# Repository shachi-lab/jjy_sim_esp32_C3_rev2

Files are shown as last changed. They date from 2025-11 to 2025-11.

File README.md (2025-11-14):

# JJY-SIM Rev.2 (JJY Time Signal Simulator for ESP32-C3)

[🇯🇵 日本語版はこちら](README_ja.md)

**JJY-SIM** is a compact time signal simulator that emulates Japan's JJY standard radio time code (40 kHz / 60 kHz) using an ESP32-C3 and the Arduino framework.  
It fetches accurate NTP time and generates a modulated JJY signal via PWM. 
**Rev.2** introduces an H-bridge RF output for higher transmission power and improved stability.

<a href="./images/jjy_sim_rev2_board_w800.jpg">
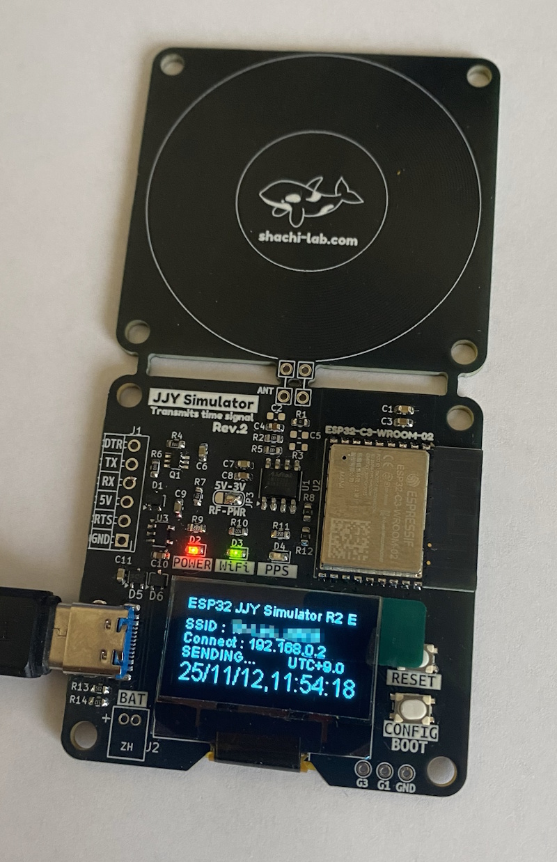
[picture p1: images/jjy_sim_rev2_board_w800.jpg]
JJY Simulator Board
</a><br/>

---

## 🪛 Features

- Compact design using **ESP32-C3 + Arduino**  
- Easy Wi-Fi setup with single-button **AP mode**  
- **OLED display** shows current time and sync status  
- Automatic time synchronization via **NTP**  
- Switchable **JJY 40 kHz (East Japan) / 60 kHz (West Japan)** output  
- Signal transmitted from a built-in **mini antenna** on the board  
- **H-bridge driver** provides high output power (⚠ may transmit farther than expected)  
- Configurable through a **web browser setup page**  
- Supports **local time zones (UTC offset)** and **DST (Daylight Saving Time)**

---

## ⚙️ How to Build

1. **Set up ESP32 boards in Arduino IDE**
   - Boards Manager URL:  
     `https://dl.espressif.com/dl/package_esp32_index.json`
   - Target board: **ESP32-C3 Dev Module**

2. **Install required libraries**
   - [WiFiManager](https://github.com/tzapu/WiFiManager)（v2.0.17 recommended）
   - [ESP8266 and ESP32 OLED driver for SSD1306 displays](https://github.com/ThingPulse/esp8266-oled-ssd1306) (v4.6.0 recommended)

3. **Open the sketch**
   - File: `JJY_Sim_ESP32_C3_REV2.ino`

4. **Compile and upload**
   - Select the correct board and COM port.
   - Click “Upload”.

> 💡 **Note:**  
ESP32-C3 uses its built-in **native USB-UART** for flashing and serial communication.  
On Windows, you may need the official **Espressif USB driver**:  
[Download here](https://www.espressif.com/en/support/download/other-tools)

> ⚠️ **First Boot:**  
During the first startup immediately after writing the program, the system builds a file system in the internal flash memory. Because of this, there may be no response for several tens of seconds, making it appear as if the system has “hung.”
Once the process is complete, the system will automatically reboot, and from then on it will start up normally. If it does not reboot automatically, please press the RESET button to restart.

---

## 📶 Wi-Fi Setup

- After power-on or reset, press the **CONFIG** switch within 5 seconds.  
- An AP named `ESP32_XXXXXXXX` starts (password: `password`).  
- Connect from your phone or PC → captive portal.
- [WiFi Configure] page → set your Wi-Fi SSID and password. 
- [Setup] page allows configuration of BAND, local time, and DST settings.

---

## 🕒 Operation

- If no button is pressed, the device connects to your Wi-Fi automatically.  
- Retrieves time from NTP server.  
- Displays current time on OLED.  
- Starts PWM JJY signal output synchronized to the next 0 second.  
- Place your radio-controlled clock near the antenna and press its “Receive” button.

---

## 🔌 Pin Assignments

| Function | GPIO | Description |
|---|---|---|
| JJY PWM Output | 10, 4 | Modulated signal (A/B for H-bridge) |
| CONFIG Switch | 9 | Wi-Fi setup (shared with BOOT) |
| ACT LED | 5 | Activity indicator |
| IND LED | 0 | Status indicator |
| OLED Reset | 2 | OLED hardware reset |
| OLED SDA | 7 | I²C data |
| OLED SCL | 6 | I²C clock |

---

## 🧾 File Structure

All Arduino source files are in the **`Source/`** folder:

```
JJY_Sim_ESP32_C3_REV2.ino   // Main sketch
wire_compat.h               // I²C compatibility header for ESP32-C3
shachi-lab_logo.h           // Logo bitmap
src/WiFiManager/            // Several files in this folder
```

---

## 📚 Dependencies

- [ESP8266 and ESP32 OLED driver for SSD1306 displays](https://github.com/ThingPulse/esp8266-oled-ssd1306)

---

## 🧰 Hardware Data

KiCad design files are included in the **`KiCad/`** folder.  
- Compatible with **KiCad v9** (older versions not supported)  
- **Gerber files** for fabrication are located in `KiCad/PLOT/`.

---

## ⚠️ Legal Notice

This device emits real low-frequency RF signals.  
Please use it responsibly and ensure compliance with local radio regulations.

---

## 🔗 Related Links

- Blog article (Japanese, detailed build notes):  
  👉 https://blog.shachi-lab.com/047_jjy_sim_rev2/

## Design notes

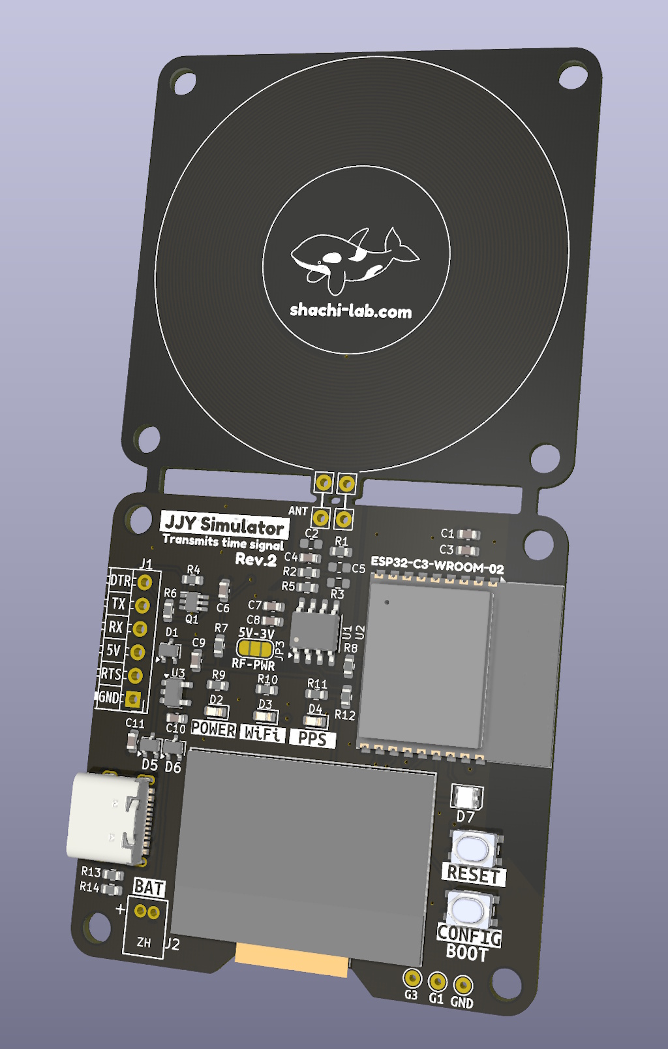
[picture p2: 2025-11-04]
KiCad/esp32_JJY_sim_C3_rev2.jpg

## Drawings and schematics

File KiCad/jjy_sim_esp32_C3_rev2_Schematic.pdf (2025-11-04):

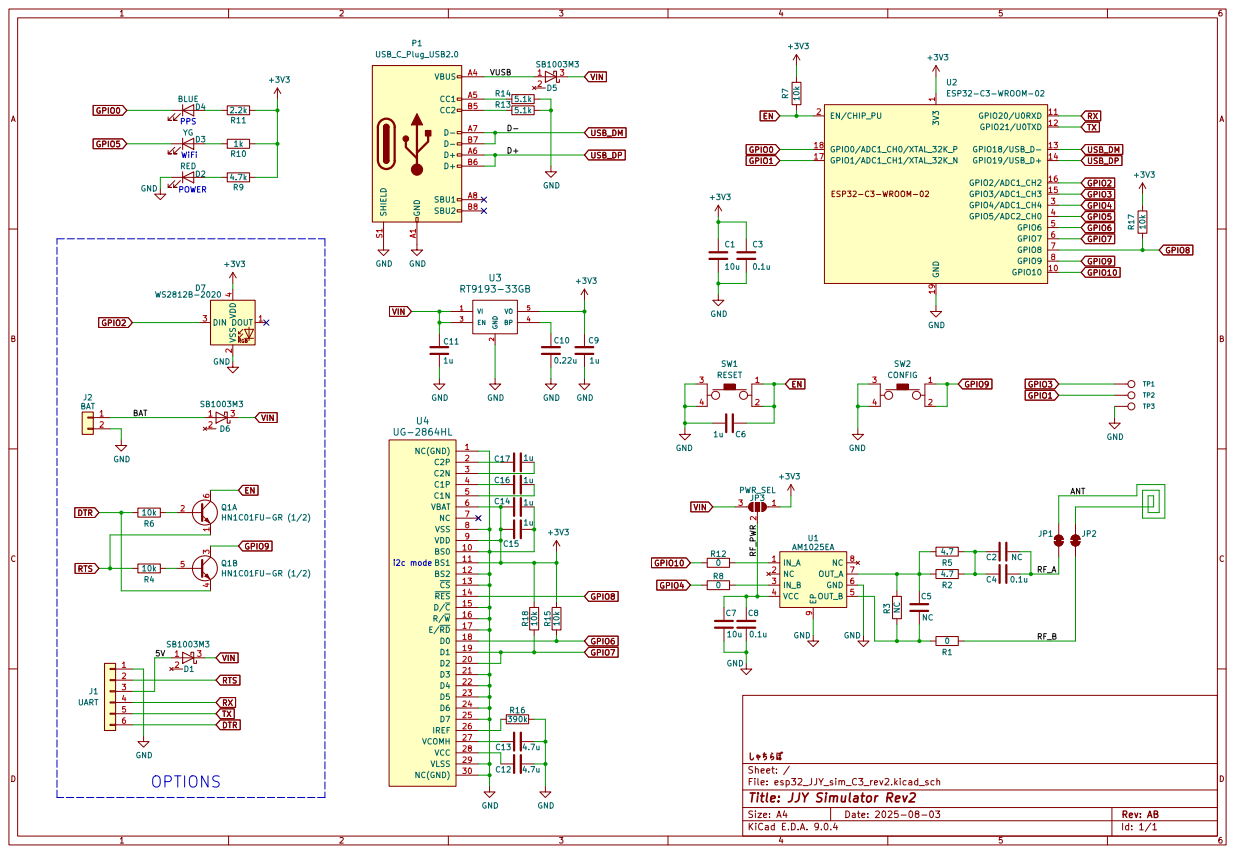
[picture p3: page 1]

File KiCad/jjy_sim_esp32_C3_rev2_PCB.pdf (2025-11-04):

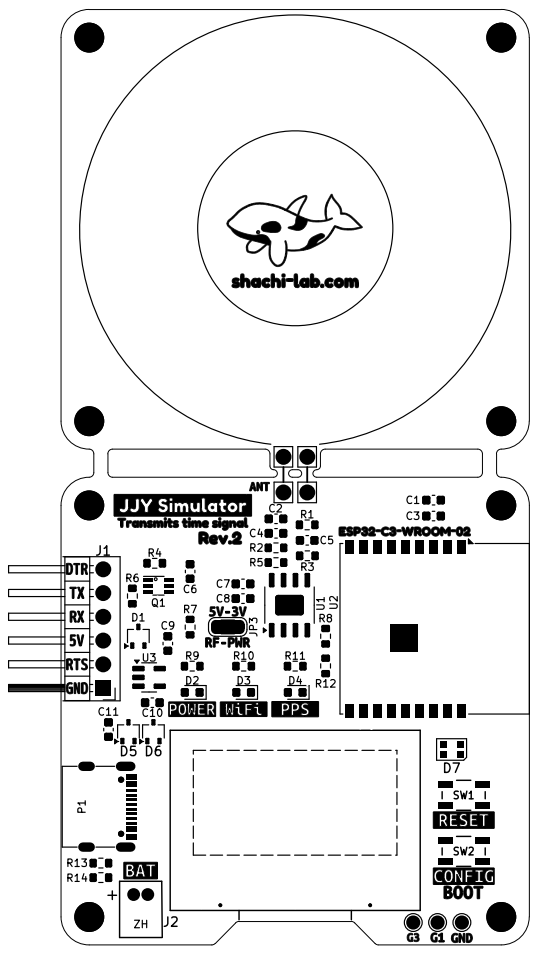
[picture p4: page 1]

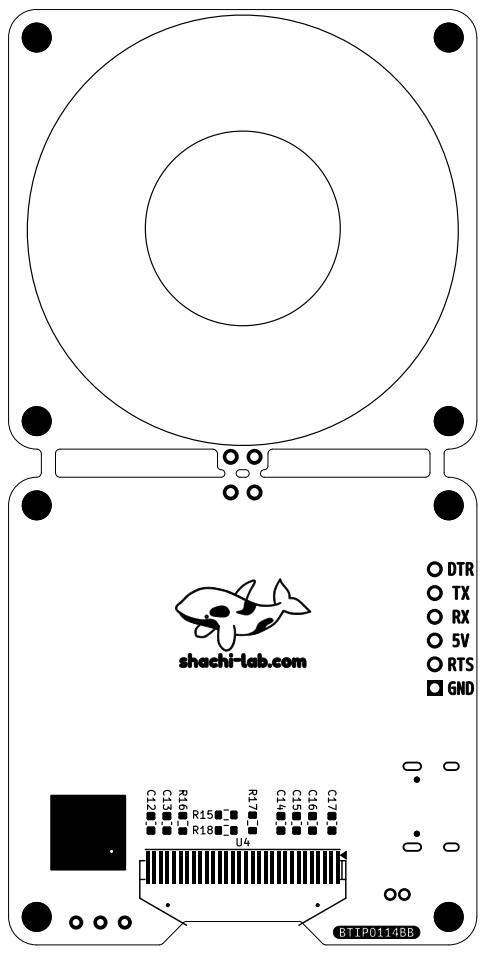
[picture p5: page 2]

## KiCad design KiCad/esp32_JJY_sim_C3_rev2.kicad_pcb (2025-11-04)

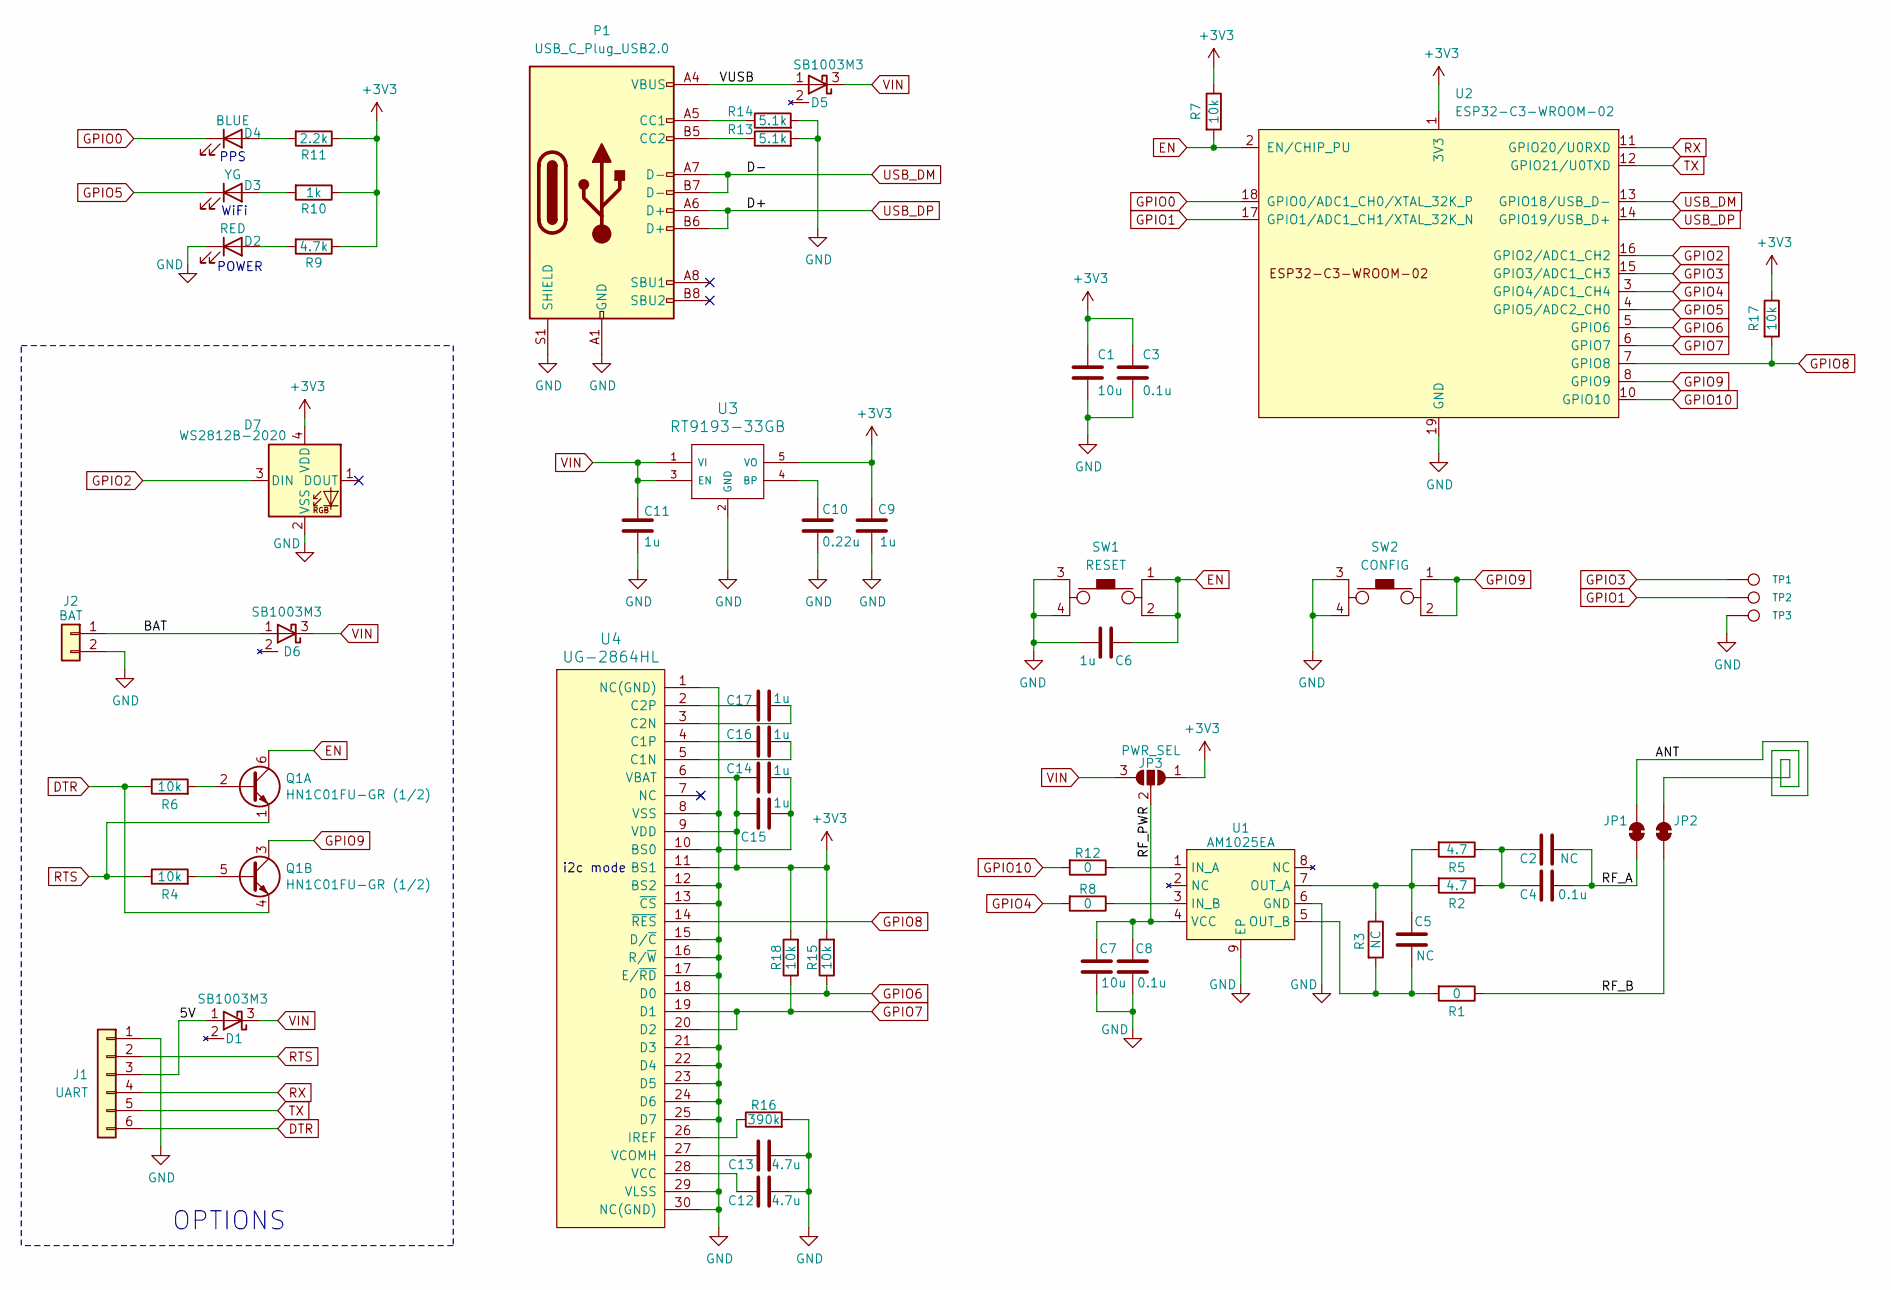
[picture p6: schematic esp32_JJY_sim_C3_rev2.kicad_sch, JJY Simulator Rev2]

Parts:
C1, C7: 10u; C_0603_1608Metric
C2, C5: NC; C_0603_1608Metric
C3, C4, C8: 0.1u; C_0603_1608Metric
C6, C9, C11, C14, C15, C16, C17: 1u; C_0603_1608Metric
C10: 0.22u; C_0603_1608Metric
C12, C13: 4.7u; C_0603_1608Metric
D1, D5, D6: SB1003M3; SOT-323_SC-70
D2: RED; LED_0603_1608Metric
D3: YG; LED_0603_1608Metric
D4: BLUE; LED_0603_1608Metric
D7: WS2812B-2020; LED_WS2812B-2020_PLCC4_2.0x2.0mm
J1: UART; PinHeader_1x06_P2.54mm_Horizontal
J2: BAT; JST_ZH_S2B-ZR_02x1.5mm_Angled
JP1: ANT-A; Jumper-2_TH_3.81mm
JP2: GND; Jumper-2_TH_3.81mm
JP3: PWR_SEL; SolderJumper-3_P1.3mm_Open_RoundedPad1.0x1.5mm_NumberLabels
P1: USB_C_Plug_USB2.0; 5077CR-16SMC2-BK-TR
Q1: HN1C01FU-GR (1/2); 2-2J1A
R1, R8, R12: 0; R_0603_1608Metric
R2, R5: 4.7; R_0603_1608Metric
R3: NC; R_0603_1608Metric
R4, R6, R7, R15, R17, R18: 10k; R_0603_1608Metric
R9: 4.7k; R_0603_1608Metric
R10: 1k; R_0603_1608Metric
R11: 2.2k; R_0603_1608Metric
R13, R14: 5.1k; R_0603_1608Metric
R16: 390k; R_0603_1608Metric
SW1: RESET; SKRPACE010
SW2: CONFIG; SKRPACE010
TP1, TP2, TP3: TP; TestPoint_THTPad_D1.5mm_Drill0.7mm
U1: AM1025EA; eSOP-8_3.9x5.05mm_EP_3.1x2.2mm_P1.27mm
U2: ESP32-C3-WROOM-02
U3: RT9193-33GB; SOT-23-5
U4: UG-2864HL; UG-2864-FPC

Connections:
+3V3: C1.1, C3.1, C9.1, C14.1, C15.1, D7.4 (VDD), JP3.1 (A), R7.1, R9.1, R10.1, R11.1, R15.2, R17.1, R18.2, U2.1 (3V3), U3.5 (VO), U4.6 (VBAT), U4.9 (VDD), U4.11 (BS1)
/5V: D1.1 (A), J1.3
/ANT: JP1.2 (B), JP2.2 (B)
/BAT: D6.1 (A), J2.1
/RF_A: C2.2, C4.2, JP1.1 (A)
/RF_B: JP2.1 (A), R1.1
/RF_PWR: C7.1, C8.1, JP3.2 (C), U1.4 (VCC)
/VUSB: D5.1 (A), P1.A4 (VBUS), P1.A9 (VBUS), P1.B4 (VBUS), P1.B9 (VBUS)
DTR: J1.6, Q1.4 (E2), R6.1
EN: C6.2, Q1.6 (C1), R7.2, SW1.1, SW1.2, U2.2 (EN/CHIP_PU)
GND: C1.2, C3.2, C6.1, C7.2, C8.2, C9.2, C10.2, C11.2, C12.2, C13.2, C14.2, C15.2, D2.1 (K), D7.2 (VSS), J1.1, J2.2, P1.A1 (GND), P1.A12 (GND), P1.B1 (GND), P1.B12 (GND), P1.S1 (SHIELD), R13.2, R14.2, R16.2, SW1.3, SW1.4, SW2.3, SW2.4, TP3.1, U1.6 (GND), U1.9 (EP), U2.9 (GND), U2.19 (GND), U3.2 (GND), U4.1 (N.C.), U4.8 (VSS), U4.10 (BS0), U4.12 (BS2), U4.13 (~CS), U4.15 (D/~C), U4.16 (R/~W), U4.17 (E/~RD), U4.21 (D3), U4.22 (D4), U4.23 (D5), U4.24 (D6), U4.25 (D7), U4.29 (VLSS), U4.30 (N.C.)
GPIO0: D4.1 (K), U2.18 (GPIO0/ADC1_CH0/XTAL_32K_P)
GPIO1: TP2.1, U2.17 (GPIO1/ADC1_CH1/XTAL_32K_N)
GPIO2: D7.3 (DIN), U2.16 (GPIO2/ADC1_CH2)
GPIO3: TP1.1, U2.15 (GPIO3/ADC1_CH3)
GPIO4: R8.2, U2.3 (GPIO4/ADC1_CH4)
GPIO5: D3.1 (K), U2.4 (GPIO5/ADC2_CH0)
GPIO6: R15.1, U2.5 (GPIO6), U4.18 (D0)
GPIO7: R18.1, U2.6 (GPIO7), U4.19 (D1), U4.20 (D2)
GPIO8: R17.2, U2.7 (GPIO8), U4.14 (~RES)
GPIO9: Q1.3 (C2), SW2.1, SW2.2, U2.8 (GPIO9)
GPIO10: R12.2, U2.10 (GPIO10)
unnamed: C2.1, C4.1, R2.1, R5.1
unnamed: D2.2 (A), R9.2
unnamed: D3.2 (A), R10.2
unnamed: D4.2 (A), R11.2
unnamed: P1.A5 (CC1), R14.1
unnamed: P1.B5 (CC2), R13.1
unnamed: Q1.2 (B1), R6.2
unnamed: Q1.5 (B2), R4.2
unnamed: R12.1, U1.1 (IN_A)
unnamed: R8.1, U1.3 (IN_B)
unnamed: C5.1, R2.2, R3.1, R5.2, U1.7 (OUT_A)
unnamed: C5.2, R1.2, R3.2, U1.5 (OUT_B)
unnamed: C10.1, U3.4 (BP)
unnamed: C16.2, U4.5 (C1N)
unnamed: C16.1, U4.4 (C1P)
unnamed: C17.2, U4.3 (C2N)
unnamed: C17.1, U4.2 (C2P)
unnamed: R16.1, U4.26 (IREF)
unnamed: C12.1, U4.28 (VCC)
unnamed: C13.1, U4.27 (VCOMH)
RTS: J1.2, Q1.1 (E1), R4.1
RX: J1.4, U2.11 (GPIO20/U0RXD)
TX: J1.5, U2.12 (GPIO21/U0TXD)
USB_DM: P1.A7 (D-), P1.B7 (D-), U2.13 (GPIO18/USB_D-)
USB_DP: P1.A6 (D+), P1.B6 (D+), U2.14 (GPIO19/USB_D+)
VIN: C11.1, D1.3 (K), D5.3 (K), D6.3 (K), JP3.3 (B), U3.1 (VI), U3.3 (EN)

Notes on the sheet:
OPTIONS
PPS
i2c mode
WiFi
POWER

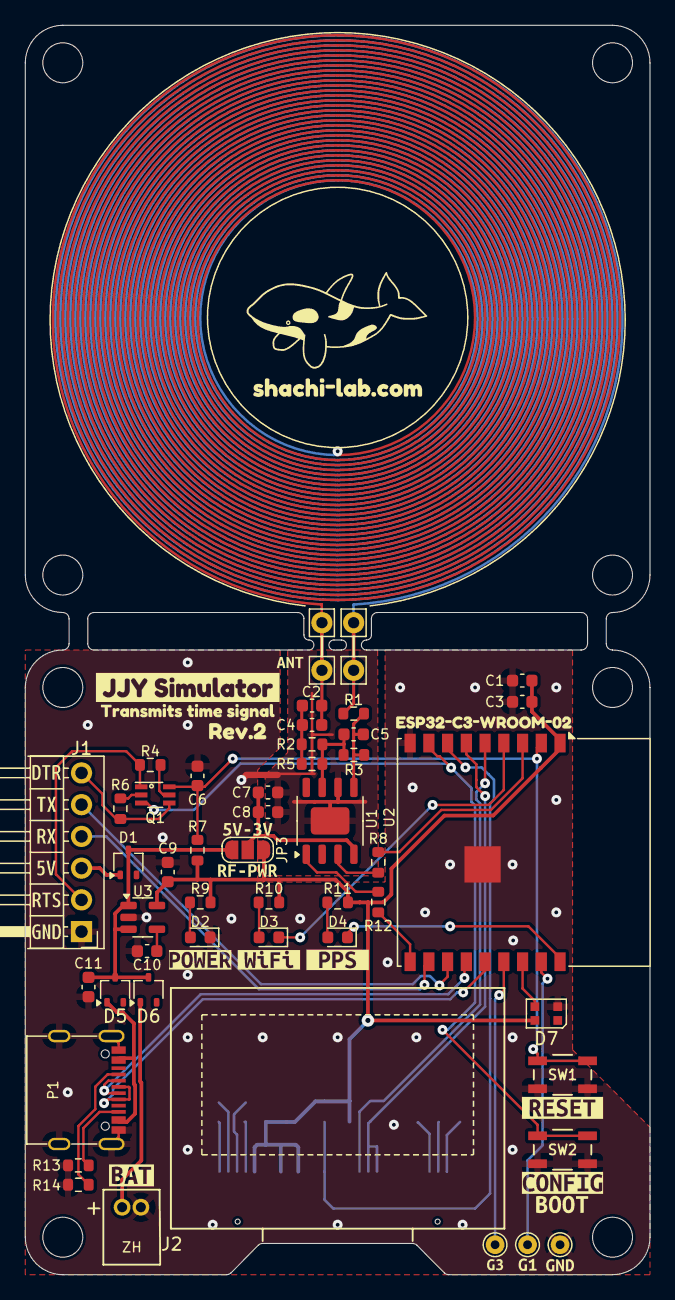
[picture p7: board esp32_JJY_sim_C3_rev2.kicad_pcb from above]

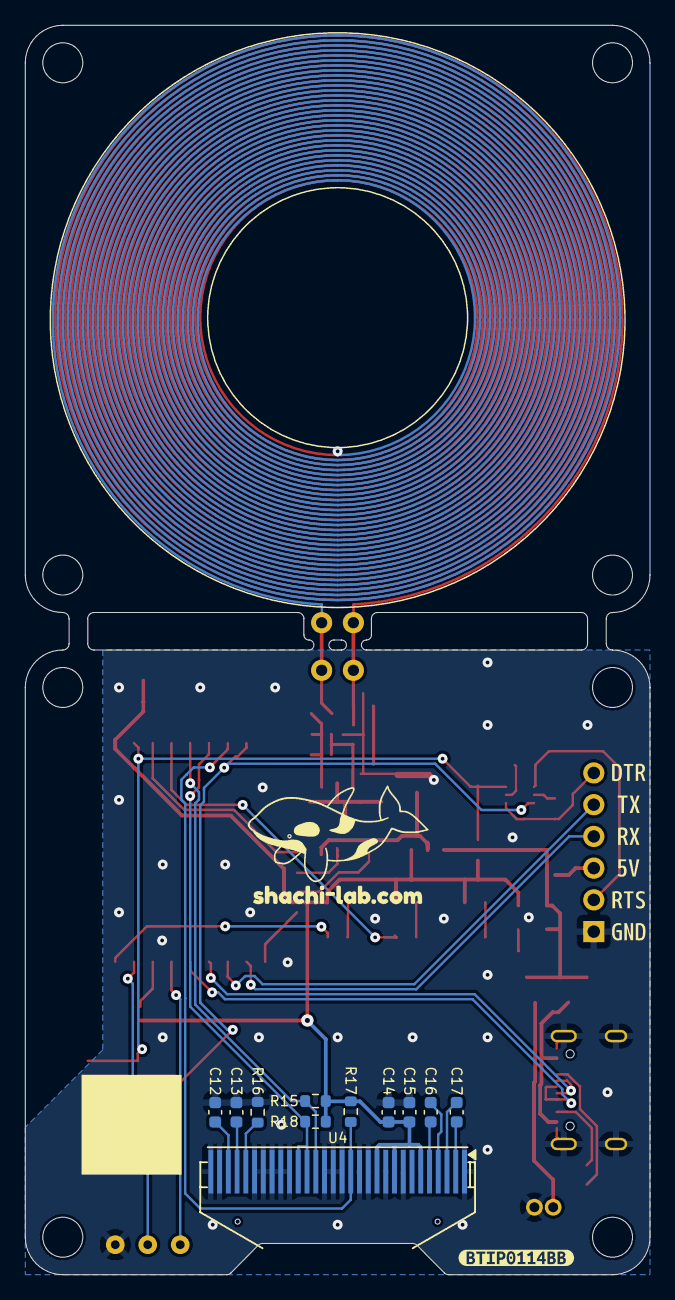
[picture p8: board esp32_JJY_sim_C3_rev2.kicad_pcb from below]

Board: 2 copper layers, 50.0 x 100.0 mm, 90 parts (19 on the bottom side), 48 nets.

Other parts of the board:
kibuzzard-1: G***; kibuzzard-6646C6AC
kibuzzard-4: G***; kibuzzard-66603A24
kibuzzard-5: G***; kibuzzard-68C580B0
kibuzzard-6: G***; kibuzzard-665BB8B1
kibuzzard-7: G***; kibuzzard-665BB8AA
kibuzzard-8: G***; kibuzzard-68D324C9
kibuzzard-9: G***; kibuzzard-665BB8A3
kibuzzard-10: G***; kibuzzard-665BB89D
kibuzzard-11: G***; kibuzzard-68D324EE
kibuzzard-12: G***; kibuzzard-669B8438
kibuzzard-13: G***; kibuzzard-665BB88E
kibuzzard-14: G***; kibuzzard-669B6BC9
kibuzzard-15: G***; kibuzzard-669B6DC4
kibuzzard-17: G***; kibuzzard-665B3587
kibuzzard-18: G***; kibuzzard-665B35C9
kibuzzard-19: G***; kibuzzard-665B357F
kibuzzard-20: G***; kibuzzard-669B16B9
kibuzzard-21: G***; kibuzzard-665A8DD6
kibuzzard-22: G***; kibuzzard-669B4532
kibuzzard-23: G***; kibuzzard-665B35AE
kibuzzard-24: G***; kibuzzard-665BBA5E
kibuzzard-25: G***; kibuzzard-665BBA64
kibuzzard-26: G***; kibuzzard-665BBA69
kibuzzard-27: G***; kibuzzard-665BBA6E
kibuzzard-28, kibuzzard-28#2: G***; kibuzzard-68D2B4BB
kibuzzard-29: G***; kibuzzard-669B8430
kibuzzard-30: G***; kibuzzard-665BBA79
kibuzzard-68D3A9C1: G***; kibuzzard-68D3A9C1
kibuzzard-68D3A910: G***; kibuzzard-68D3A910
kibuzzard-68DDC93A: G***; kibuzzard-68DDC93A
kibuzzard-68E061D7: G***; kibuzzard-68E061D7

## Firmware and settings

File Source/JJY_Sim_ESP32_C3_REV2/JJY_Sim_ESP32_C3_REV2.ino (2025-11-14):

/*
 * JJY Simulater Rev.2
 * ESP32-C3-WROOM-02
 * 
 * ファイル/環境設定の追加のボードマネージャに
 * "https://dl.espressif.com/dl/package_esp32_index.json" を追加
 * 
 * platform = espressif32
 * board = ESP32C3 Dev Module
 *
 * PWM出力   = A:IO10, B:IO4
 * OLED(I2C) = SCL:IO6, SDA:IO7, RSES:IO8 
 */
#include <WiFi.h>
#include <time.h>
#include <Wire.h>           // Only needed for Arduino 1.6.5 and earlier
#include "wire_compat.h"
#include <OLEDDisplayUi.h>  // https://github.com/ThingPulse/esp8266-oled-ssd1306
#include <SSD1306Wire.h>    //
#include <WiFiManager.h>    // https://github.com/tzapu/WiFiManager
#include <FS.h>
#include <SPIFFS.h>
#include <driver/ledc.h>
#include <Preferences.h>
#include "shachi-lab_logo.h"

#define PRODUCT_NAME_STR  "ESP32 JJY Simulator R2"
#define VERSION_STR       "Version 2.1.1"

#define FORMAT_SPIFFS_IF_FAILED true

#undef  BUILTIN_LED
#define BUILTIN_LED       0       // GPIO0
#define PIN_LED_WAVE      BUILTIN_LED
#define PIN_LED_WIFI      5       // GPIO5
#define PIN_CONFIG        9       // GPIO9
#define PIN_OLED_RES      8       // GPIO8
#define PIN_OLED_SCL      6       // GPIO6
#define PIN_OLED_SDA      7       // GPIO7
#define PIN_PWM_A         10      // GPIO10
#define PIN_PWM_B         4       // GPIO4

#define OLED_I2CADR       0x3c

#define LED_ON            0
#define LED_OFF           1
#define LED_BLINK         2

#define JJY_TYPE_EAST     false     // East (40kHz)
#define JJY_TYPE_WEST     true      // West (60kHz)
#define JJY_FREQ_EAST     40000
#define JJY_FREQ_WEST     60000
#define JJY_STR_EAST      "E"
#define JJY_STR_WEST      "W"
#define JJY_TYPE_STR(type)  (!type ? JJY_STR_EAST : JJY_STR_WEST)
#define JJY_TYPE_FREQ(type) (!type ? JJY_FREQ_EAST : JJY_FREQ_WEST)

#define CONFIG_WAIT_TIME  5000    // msec
#define CONFIG_WAIT_TICK  100     // msec

#define PWM_BITS          7
#define PWM_DUTY_MAX      ((1 << PWM_BITS) - 1)
#define PWM_DUTY_ON       (PWM_DUTY_MAX / 2)
#define PWM_CH_A          LEDC_CHANNEL_0
#define PWM_CH_B          LEDC_CHANNEL_1
#define PWM_DEAD          0

#define JJY_T_BIT0        800
#define JJY_T_BIT1        500
#define JJY_T_PM          200

#define JJY_BIT_ZERO      0
#define JJY_BIT_PMn       -1
#define JJY_BIT_PM0       -2
#define JJY_BIT_OFF       -3

String WiFi_ssid = "ssid";
String WiFi_pass = "pass";
String WiFi_time = "";
String WiFi_ip   = "";
char timeNowStr[64] = "";

SSD1306Wire display(OLED_I2CADR, PIN_OLED_SDA, PIN_OLED_SCL);  

WiFiManager wm; // global wm instance
WiFiManagerParameter custom_field; // global param ( for non blocking w params )

Preferences prefs;

#define TIMEZONE_JAPAN    9.0

bool JJY_type = false;
int JJY_freq = JJY_FREQ_EAST;
String JJY_str = JJY_STR_EAST;
float timezone_offset = TIMEZONE_JAPAN;
String tz_str = "";
bool daylight_flag = false;
int config_wait_remain = 0;

#define TIMEZONE_SEC      (long)(timezone_offset * 3600.0)
#define DAYLIGHT_SEC      (daylight_flag ? 3600 : 0)
#define JJY_DAYLIGHT_BIT  (daylight_flag ? 1 : 0)

/*
*  初期化
*/
void setup() {

  bool conn_flag = false;

  led_blink(PIN_LED_WIFI, LED_ON);
  led_blink(PIN_LED_WAVE, LED_ON);
  disp_screen(0);
  delay(500);

  Serial.begin(115200);
  Serial.println();
  Serial.println(PRODUCT_NAME_STR);
  Serial.println(VERSION_STR);
  delay(1500);

  if (!SPIFFS.begin(FORMAT_SPIFFS_IF_FAILED)) {
    go_reboot("SPIFFS Mount Failed");
    for(;;);
  }
  
  get_settings();

  Serial.println("JJY_FREQ = " + String(JJY_freq) + " : " + JJY_str ); 
  Serial.println(tz_str);

  disp_screen(1);

  pinMode(PIN_CONFIG, INPUT_PULLUP);  
  led_blink(PIN_LED_WIFI, LED_OFF);
  led_blink(PIN_LED_WAVE, LED_OFF);

  WiFi.mode(WIFI_STA); // explicitly set mode, esp defaults to STA+AP  

  led_blink(PIN_LED_WAVE, LED_ON);

  for(int i = CONFIG_WAIT_TIME/CONFIG_WAIT_TICK; i; i-- ) {
    config_wait_remain = i / (1000/CONFIG_WAIT_TICK) + 1;
    disp_screen(-1);

    delay(CONFIG_WAIT_TICK);
    if(digitalRead(PIN_CONFIG) != LOW) continue;

    disp_screen(-2);
    led_blink(PIN_LED_WAVE, LED_BLINK);
    Serial.println("Enter to CONFIG mode");

    config_mode_setup();

    if (!wm.startConfigPortal()) {
      go_reboot("failed to connect / timeout");
    }
    conn_flag = true;
    get_settings();
    break;
  }

  WiFi_ssid = wm.getWiFiSSID();
  WiFi_pass = wm.getWiFiPass();
  Serial.println("ssid : " + WiFi_ssid);
//Serial.println("pass : " + WiFi_pass);

  disp_screen(2);
  led_blink(PIN_LED_WAVE, LED_OFF);

  wm.setDebugOutput(false);

  if( !conn_flag ) {
    Serial.println("Connecting....");
    led_blink(PIN_LED_WIFI, LED_BLINK);

    if(!wm.autoConnect()) {
      go_reboot("Failed to connect");
    } 
  }

  if( WiFi.status() == WL_CONNECTED ){

    conn_flag = true;
    Serial.println("connected...");
    Serial.print  ("IP Address:");
    Serial.println(WiFi.localIP());
  
    led_blink(PIN_LED_WIFI, LED_ON);
//  digitalWrite(5,0);

    disp_screen(4);  

  }else
  { 
    go_reboot("Connect timeout.");
  }

  configTime( TIMEZONE_SEC, DAYLIGHT_SEC, "ntp.nict.jp", "ntp.jst.mfeed.ad.jp");

  pwm_setup();
}

/*
 * メインループ
 */
void loop() {

  static int radio_output_stat = 0;
  static int last_min = 99;

  struct tm *tm;
  tm = get_time_now();
  if ( tm == NULL ) return; 

  if ( timeNowStr[0] == '\0' ) {
      Serial.printf(".");
      disp_screen(5);
      return;
  }

  disp_screen(6 + radio_output_stat);

  if( tm->tm_sec != 0 ) return;
  if( tm->tm_min == last_min ) return;
  last_min = tm->tm_min;

  Serial.println();
  Serial.printf("%s > ", timeNowStr);

  radio_output_stat = 1;

  jjy_output( tm );

  led_blink(PIN_LED_WAVE, LED_ON);
}

/*
* 再起動処理
*/
void go_reboot(String text)
{
  led_blink(PIN_LED_WIFI, LED_ON);
  led_blink(PIN_LED_WAVE, LED_ON);
  Serial.println(text);
  Serial.println("reboot!!");
  disp_screen(3);

  led_blink(PIN_LED_WIFI, LED_OFF);
  led_blink(PIN_LED_WAVE, LED_OFF);

  //reset and try again, or maybe put it to deep sleep
  ESP.restart();
  delay(5000);
}

/*
* LEDを点滅
*/
void led_blink(uint8_t pin, uint8_t mode)
{
  static bool attached[16] = { 0 };

  if( mode == LED_BLINK ) {
    if( !attached[pin] ) ledcAttach(pin, 4, 14);
    attached[pin] = true;
    ledcWrite(pin, 8192);
  } else {
    if( attached[pin] ) ledcDetach(pin);
    attached[pin] = false;
    pinMode(pin, OUTPUT);  
    digitalWrite(pin, mode == LED_OFF);
  }
}

/*
* OLEDの画面描画
*/
void disp_screen( int mode )
{
  if(mode == 0) {
    pinMode(PIN_OLED_RES, OUTPUT); 
    digitalWrite(PIN_OLED_RES, 0);
    delay(10);
    digitalWrite(PIN_OLED_RES, 1);
    delay(10);
  
    // Initialising the UI will init the display too.
    display.init();
    display.flipScreenVertically();

    display.drawXbm(0, 0, shachilab_logo_width, shachilab_logo_height, shachilab_logo_bits);
    display.display();
    return;
  }

  display.clear();
  display.setFont(ArialMT_Plain_10);

  display.drawString( 0,  0, PRODUCT_NAME_STR " " + JJY_str );

  if( mode == -1 ){
    display.drawString( 0, 15, VERSION_STR );    
    display.drawString( 0, 25, "Waiting for CONFIG" );
    display.drawString( 0, 35, String(config_wait_remain) + " sec left" );
  }
  if( mode == -2 ){  
    display.drawString( 0, 15, "Enter to CONFIG mode" );
  }

  if( mode > 1 ) {
    display.drawString( 0, 15, "SSID : " + WiFi_ssid );
  }
  if( mode == 2 ) {
    display.drawString( 0, 25, "Connecting..." );
  } else
  if( mode == 3 ) {
      display.drawString( 0, 25, "Connect timeout");
      display.drawString( 0, 35, "Reboot now!!" );
  } else
  if( mode > 3 ) {
      display.drawString( 0, 25, "Connect : " + WiFi.localIP().toString());
  }
  if( mode > 4 ) {
    display.drawString( 78, 35, tz_str );
  }
  if( mode == 6 ){
    display.drawString( 0, 35, "WAITING 00s" );
  } else
  if( mode > 6 ) {
    display.drawString( 0, 35, "SENDING..." );
  }
  if( mode == 5 ) {
    display.drawString( 0, 35, "SYNC NTP...");
  } else
  if( mode > 5 ) {
    display.setFont(ArialMT_Plain_16);
    display.drawString( 0, 46, timeNowStr);
  }
  display.display();
}

/*
* 現在時刻を取得
*/
struct tm *get_time_now()
{
  static time_t time_last = 0;

  time_t now = time(NULL) + DAYLIGHT_SEC;
  if( time_last == now )  return NULL;
  time_last = now;

  struct tm *tm = localtime( &time_last );
  if( tm == NULL ) return NULL;

  if( tm->tm_year < 100 )
  {
      timeNowStr[0] = '\0';
      return tm;
  }
  tm->tm_year -= 100;
  sprintf(timeNowStr, "%02d/%02d/%02d,%02d:%02d:%02d",
    tm->tm_year, tm->tm_mon+1, tm->tm_mday, tm->tm_hour, tm->tm_min, tm->tm_sec);

  return tm;
}

/*
* PWM(Hブリッジ)の初期設定
*/
void pwm_setup()
{
  pinMode(PIN_PWM_A, OUTPUT);                 
  ledcAttachChannel(PIN_PWM_A, JJY_freq, PWM_BITS, PWM_CH_A);

  pinMode(PIN_PWM_B, OUTPUT);                 
  ledcAttachChannel(PIN_PWM_B, JJY_freq, PWM_BITS, PWM_CH_B);

  pwm_stop();
}

// PWM出力
void pwm_on()
{
  ledc_set_duty_with_hpoint(LEDC_LOW_SPEED_MODE, PWM_CH_A, PWM_DUTY_ON-PWM_DEAD, PWM_DEAD); 
  ledc_set_duty_with_hpoint(LEDC_LOW_SPEED_MODE, PWM_CH_B, PWM_DUTY_ON-PWM_DEAD, PWM_DUTY_ON+PWM_DEAD); 

  ledc_update_duty( LEDC_LOW_SPEED_MODE, PWM_CH_A );
  ledc_update_duty( LEDC_LOW_SPEED_MODE, PWM_CH_B );
}

// 出力をブレーキするとき（Hブリッジブレーキ）
void pwm_off()
{
  ledcWriteChannel(PWM_CH_A, PWM_DUTY_MAX);
  ledcWriteChannel(PWM_CH_B, PWM_DUTY_MAX);
}

// 出力を止るとき（Hブリッジ休止）
void pwm_stop()
{
  ledcWriteChannel(PWM_CH_A, 0);
  ledcWriteChannel(PWM_CH_B, 0);
}

/*
 * JJYの1ビットを出力 
 */
void jjy_put_bit( int flag )
{
  int t_on;
  char ch;

  if( flag == JJY_BIT_OFF ){
    t_on = 0;
    ch = '.';
  }else
  if( flag == JJY_BIT_PMn ){
    t_on = JJY_T_PM;
    ch = '-';
  }else
  if( flag == JJY_BIT_PM0 ){
    t_on = JJY_T_PM;
    ch = '-';
  }else
  if( flag == JJY_BIT_ZERO )
  {
    t_on = JJY_T_BIT0;
    ch = '0';
  }else
  {
    t_on = JJY_T_BIT1;
    ch = '1';
  }
  Serial.write( ch );

  if( t_on ) {
    pwm_on();
  }
  digitalWrite(BUILTIN_LED, LED_ON);
  delay( 3 );   
  digitalWrite(BUILTIN_LED, LED_OFF);
  if( t_on ) {
    delay( t_on - 3 );
    pwm_off();
  }

  if( flag == JJY_BIT_PM0 ) {
    return;
  }
  while ( get_time_now() == NULL ) delay(1);
  disp_screen(7);
}

/*
 * intをBCDに変換
 */
int get_int_to_bcd( int n )
{
  int res = n % 10;
  res += ((n/ 10)%10)<<4;
  res += ((n/100)%10)<<8;
  return res;
}

/*
 * 偶数パリティを計算
 */
int get_even_parity( int n )
{
  n ^= n >> 8;
  n ^= n >> 4;
  n ^= n >> 2;
  n ^= n >> 1;
  return n & 1;
}

/*
 * JJYフォーマットを出力
 */
void jjy_output( struct tm *tm )
{
const int totalDaysOfMonth[] = {0,31,59,90,120,151,181,212,243,273,304,334 };
  int totalDays = totalDaysOfMonth[tm->tm_mon];
  totalDays += tm->tm_mday;
  if(((tm->tm_year & 0x03)==0) && (tm->tm_mon > 2)) totalDays++;

  int mm = get_int_to_bcd( tm->tm_min );
  int hh = get_int_to_bcd( tm->tm_hour );
  int dd = get_int_to_bcd( totalDays );
  int yy = get_int_to_bcd( tm->tm_year % 100 );
  int pa1= get_even_parity( hh );
  int pa2= get_even_parity( mm );
  int ww = tm->tm_wday;

  jjy_put_bit( JJY_BIT_PMn );   // :00 M
  jjy_put_bit( mm & 0x40 );     // :01
  jjy_put_bit( mm & 0x20 );     // :02
  jjy_put_bit( mm & 0x10 );     // :03
  jjy_put_bit( 0 );             // :04
  jjy_put_bit( mm & 0x08 );     // :05
  jjy_put_bit( mm & 0x04 );     // :06
  jjy_put_bit( mm & 0x02 );     // :07
  jjy_put_bit( mm & 0x01 );     // :08
  jjy_put_bit( JJY_BIT_PMn );   // :09 P1
  jjy_put_bit( 0 );             // :10
  jjy_put_bit( 0 );             // :11
  jjy_put_bit( hh & 0x20 );     // :12
  jjy_put_bit( hh & 0x10 );     // :13
  jjy_put_bit( 0 );             // :14
  jjy_put_bit( hh & 0x08 );     // :15
  jjy_put_bit( hh & 0x04 );     // :16
  jjy_put_bit( hh & 0x02 );     // :17
  jjy_put_bit( hh & 0x01 );     // :18
  jjy_put_bit( JJY_BIT_PMn );   // :19 P2
  jjy_put_bit( 0 );             // :20
  jjy_put_bit( 0 );             // :21
  jjy_put_bit( dd & 0x200 );    // :22
  jjy_put_bit( dd & 0x100 );    // :23
  jjy_put_bit( 0 );             // :24
  jjy_put_bit( dd & 0x80 );     // :25
  jjy_put_bit( dd & 0x40 );     // :26
  jjy_put_bit( dd & 0x20 );     // :27
  jjy_put_bit( dd & 0x10 );     // :28
  jjy_put_bit( JJY_BIT_PMn );   // :29 P3
  jjy_put_bit( dd & 0x08 );     // :30
  jjy_put_bit( dd & 0x04 );     // :31
  jjy_put_bit( dd & 0x02 );     // :32
  jjy_put_bit( dd & 0x01 );     // :33
  jjy_put_bit( 0 );             // :34
  jjy_put_bit( 0 );             // :35
  jjy_put_bit( pa1 );           // :36 PA1
  jjy_put_bit( pa2 );           // :37 PA2
  jjy_put_bit( 0 );             // :38 SU1
  jjy_put_bit( JJY_BIT_PMn );   // :39 P4
  
  if (tm->tm_min == 15 || tm->tm_min == 45) {
    jjy_put_bit( JJY_BIT_OFF );     // :40  
    jjy_put_bit( JJY_BIT_OFF );     // :41  
    jjy_put_bit( JJY_BIT_OFF );     // :42  
    jjy_put_bit( JJY_BIT_OFF );     // :43  
    jjy_put_bit( JJY_BIT_OFF );     // :44  
    jjy_put_bit( JJY_BIT_OFF );     // :45  
    jjy_put_bit( JJY_BIT_OFF );     // :46  
    jjy_put_bit( JJY_BIT_OFF );     // :47  
    jjy_put_bit( JJY_BIT_OFF );     // :48  
    ww = 0;
 }
 else {
    jjy_put_bit( JJY_DAYLIGHT_BIT );// :40 SU2
    jjy_put_bit( yy & 0x80 );       // :41
    jjy_put_bit( yy & 0x40 );       // :42
    jjy_put_bit( yy & 0x20 );       // :43
    jjy_put_bit( yy & 0x10 );       // :44
    jjy_put_bit( yy & 0x08 );       // :45
    jjy_put_bit( yy & 0x04 );       // :46
    jjy_put_bit( yy & 0x02 );       // :47
    jjy_put_bit( yy & 0x01 );       // :48
  }
  jjy_put_bit( JJY_BIT_PMn );   // :49 P5
  jjy_put_bit( ww & 0x04 );     // :50
  jjy_put_bit( ww & 0x02 );     // :51
  jjy_put_bit( ww & 0x01 );     // :52
  jjy_put_bit( 0 );             // :53 LS1
  jjy_put_bit( 0 );             // :54 LS2
  jjy_put_bit( 0 );             // :55
  jjy_put_bit( 0 );             // :56
  jjy_put_bit( 0 );             // :57
  jjy_put_bit( 0 );             // :58
  jjy_put_bit( JJY_BIT_PM0 );   // :59 P0
}

/*
* 設定を取得
*/
void get_settings()
{
  prefs.begin("jjy", true);
  JJY_type = prefs.getInt("type", false);                 // default = false (40kHz)
  timezone_offset = prefs.getFloat("tz", TIMEZONE_JAPAN); // default = 9.0 (Japan)
  daylight_flag = prefs.getBool("dst", false);            // default = false 
  prefs.end();
  if( timezone_offset < -12.0 || timezone_offset > 12.0 ) timezone_offset = TIMEZONE_JAPAN;

  if (JJY_type == JJY_TYPE_EAST) {
      JJY_freq = JJY_FREQ_EAST;
      JJY_str = JJY_STR_EAST;
  } else {
      JJY_freq = JJY_FREQ_WEST;
      JJY_str = JJY_STR_WEST;
  }
  tz_str = "UTC" + String((timezone_offset >= 0 ? "+" : "")) + String(timezone_offset, 1);
  if (daylight_flag) tz_str += "*";
}

/*
* 設定を保存
*/
void put_settings()
{
  prefs.begin("jjy", false);
  prefs.putBool("type", JJY_type);      // true / false
  prefs.putFloat("tz", timezone_offset);// -12.0 ～ +12.0
  prefs.putBool("dst", daylight_flag);  // true / false
  prefs.end();
}


/*
* timezoneのoptionタグ作成
*/
String opt(float val, const char* label) {
  String s = "<option value='";
  s += String(val, 1);
  s += "'";
  if (abs(val - timezone_offset) < 0.01) s += " selected";
  s += ">";
  s += label;
  s += "</option>";
  return s;
}

/*
* 現在値を反映したHTML生成
*/
void build_config_html()
{
  static String page;
  
  page = "<h1>Setup</h1>";
  page += 
    "<label for=\"type\">Band :</label>"
    "<select id=\"type\" name=\"type\">"
    "<option value=\"0\"";
  if (JJY_type == JJY_TYPE_EAST) page += " selected";
  page +=
    ">40 kHz (East)</option>"
    "<option value=\"1\"";
  if (JJY_type != JJY_TYPE_EAST) page += " selected";
  page +=
    ">60 kHz (West)</option>"
    "</select>"
    "<br><br>";

  page += 
    "<label for=\"tz\">Timezone :</label>"
    "<select id=\"tz\"name=\"tz\">";
	page += opt(-12.0, "(UTC−12:00) Baker Island");
	page += opt(-11.0, "(UTC−11:00) American Samoa");
	page += opt(-10.0, "(UTC−10:00) Hawaii");
	page += opt(-9.0,  "(UTC−09:00) Alaska");
	page += opt(-8.0,  "(UTC−08:00) Los Angeles / Pacific Time");
	page += opt(-7.0,  "(UTC−07:00) Denver / Mountain Time");
	page += opt(-6.0,  "(UTC−06:00) Chicago / Central Time");
	page += opt(-5.0,  "(UTC−05:00) New York / Eastern Time");
	page += opt(-4.0,  "(UTC−04:00) Santiago / Atlantic Time");
	page += opt(-3.5,  "(UTC−03:30) Newfoundland");
	page += opt(-3.0,  "(UTC−03:00) Buenos Aires / São Paulo");
	page += opt(-2.0,  "(UTC−02:00) South Georgia");
	page += opt(-1.0,  "(UTC−01:00) Azores");
	page += opt( 0.0,  "(UTC±00:00) London / Lisbon");
	page += opt( 1.0,  "(UTC＋01:00) Berlin / Paris");
	page += opt( 2.0,  "(UTC＋02:00) Cairo / Athens");
	page += opt( 3.0,  "(UTC＋03:00) Moscow / Nairobi");
	page += opt( 3.5,  "(UTC＋03:30) Tehran");
	page += opt( 4.0,  "(UTC＋04:00) Dubai / Baku");
	page += opt( 4.5,  "(UTC＋04:30) Kabul");
	page += opt( 5.0,  "(UTC＋05:00) Karachi / Tashkent");
	page += opt( 5.5,  "(UTC＋05:30) India / Colombo");
	page += opt( 5.75, "(UTC＋05:45) Nepal");
	page += opt( 6.0,  "(UTC＋06:00) Dhaka / Almaty");
	page += opt( 6.5,  "(UTC＋06:30) Yangon / Cocos Islands");
	page += opt( 7.0,  "(UTC＋07:00) Bangkok / Jakarta");
	page += opt( 8.0,  "(UTC＋08:00) Beijing / Singapore");
	page += opt( 9.0,  "(UTC＋09:00) Tokyo / Seoul");
	page += opt( 9.5,  "(UTC＋09:30) Darwin / Adelaide");
	page += opt(10.0,  "(UTC＋10:00) Sydney / Guam");
	page += opt(11.0,  "(UTC＋11:00) Solomon Islands / Magadan");
	page += opt(12.0,  "(UTC＋12:00) Fiji / Auckland");
	page += opt(13.0,  "(UTC＋13:00) Tonga / Samoa");
  page += "</select><br><br>";

  page +=
    "<input type='checkbox' id='dst' name='dst' value='1'";
  if (daylight_flag) page += " checked";
  page +=
    ">"
    "<label for=\"dst\">DST(Summer Time)</label>"
    "<br><br>";

  new (&custom_field) WiFiManagerParameter(page.c_str()); // custom html input
  if (wm.getParametersCount() == 0 ) {
    wm.addParameter(&custom_field);
  }
}

/*
* 設定画面
*/
void config_mode_setup()
{
  build_config_html();

  wm.setSaveParamsCallback(saveParamCallback);
  std::vector<const char *> menu = {"wifi","info","param","sep","restart","exit"};
  wm.setMenu(menu);
  // set dark theme
  wm.setClass("invert");
  wm.setConfigPortalTimeout(120);
}

/*
* POSTパラメーターを取得する
*/
String getParam(String name)
{
  //read parameter from server, for customhmtl input
  String value;
  if(wm.server->hasArg(name)) {
    value = wm.server->arg(name);
  }
  return value;
}

/*
* SVAEコールバック
*/
void saveParamCallback(){
  Serial.println("[CALLBACK] saveParamCallback fired");

  String para_freq = getParam("type");
  String para_tz = getParam("tz");
  String para_dst = getParam("dst");

  Serial.println("PARAM freq = " + para_freq);
  JJY_type = atoi(para_freq.c_str()) != 0;

  Serial.println("PARAM tz = " + para_tz);
  timezone_offset = atof(para_tz.c_str());

  Serial.println("PARAM dst = " + para_dst);
  daylight_flag = atoi(para_dst.c_str()) != 0;

  put_settings();
  build_config_html();
}

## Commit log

2025-11-04 1st commit
    [esp32_JJY_sim_C3_rev2.kicad_pcb, esp32_JJY_sim_C3_rev2.kicad_sch]
2025-11-04 Added Gerber data files
    [esp32_JJY_sim_C3_rev2-B_Cu.gbl, esp32_JJY_sim_C3_rev2-B_Mask.gbs, esp32_JJY_sim_C3_rev2-B_Paste.gbp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]
2025-11-10 Fix minor bugs and add Shachi-lab logo display
    [JJY_Sim_ESP32_C3_REV2.ino]
2025-11-10 Switch to English README as main
    - Set English README.md as the default main document
    - Moved Japanese version to README_ja.md
    - Updated internal links
2026-01-26 3DPrintを変更 - Topに不透明用を追加 - Bottomにロゴ追加
